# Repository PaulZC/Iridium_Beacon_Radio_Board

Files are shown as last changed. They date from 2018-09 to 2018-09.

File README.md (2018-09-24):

# Iridium 9603N Beacon Radio Board

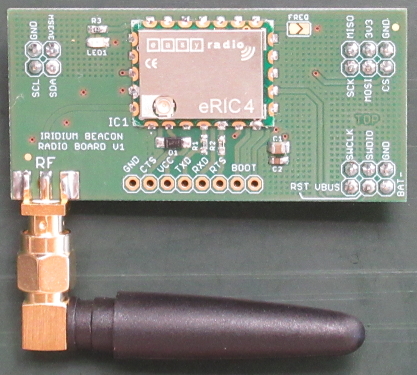
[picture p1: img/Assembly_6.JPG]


A radio board for the [Iridium 9603N Beacon](https://github.com/PaulZC/Iridium_9603_Beacon). Equipped with an
[LPRS eRIC4 or eRIC9 integrated radio module](http://www.lprs.co.uk/products/easyradio-ism-modules/eric-soc-rf-modules.html),
this board allows remote control of radio-enabled devices near the Iridium Beacon. E.g. a
[radio-enabled cut-down device](https://github.com/PaulZC/Pyrotechnic_Balloon_Cut-Down).

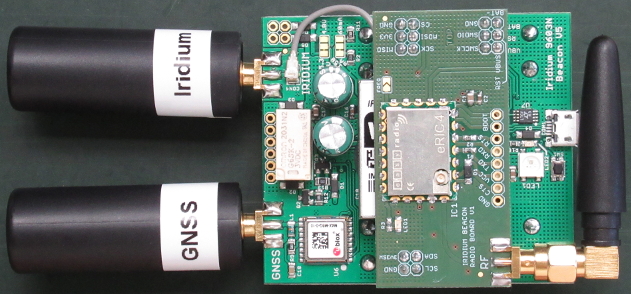
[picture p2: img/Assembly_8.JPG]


See [ASSEMBLY.md](https://github.com/PaulZC/Iridium_Beacon_Radio_Board/blob/master/ASSEMBLY.md) for details on how to assemble the PCB.

See [Iridium_Beacon_Radio_Board_V1.pdf](https://github.com/PaulZC/Iridium_Beacon_Radio_Board/blob/master/Iridium_Beacon_Radio_Board_V1.pdf) for the schematic,
layout and Bill Of Materials.

The [Eagle](https://github.com/PaulZC/Iridium_Beacon_Radio_Board/tree/master/Eagle) directory contains the schematic and pcb design files.

### License

This project is distributed under a Creative Commons Attribution + Share-alike (BY-SA) licence.
Please refer to section 5 of the licence for the “Disclaimer of Warranties and Limitation of Liability”.

Enjoy!

**_Paul_**

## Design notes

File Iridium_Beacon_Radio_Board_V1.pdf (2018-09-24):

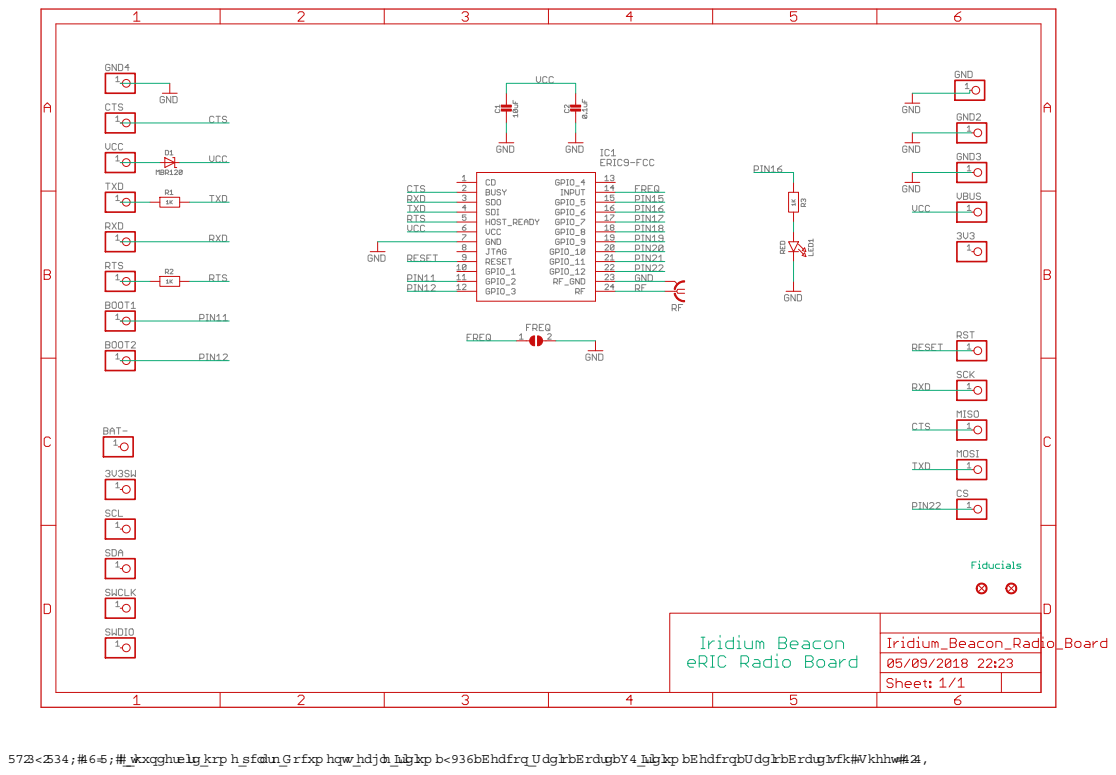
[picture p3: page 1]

thunderbird\hom e\pclark\D ocum ents\eagle\Iridium _9603_Beacon\R adio_Board_V1\Iridium _Beacon_R adio_Board.sch (Sheet: 1/1)

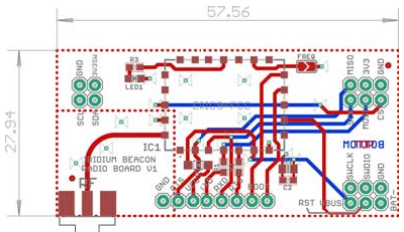
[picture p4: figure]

24/09/2018 13:29 \\thunderbird\hom e\pclark\D ocum ents\eagle\Iridium _9603_Beacon\R adio_Board_V1\Iridium _Beacon_R adio_Bo

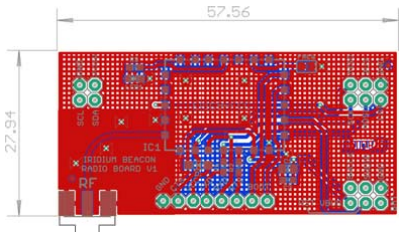
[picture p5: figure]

24/09/2018 13:29 \\thunderbird\hom e\pclark\D ocum ents\eagle\Iridium _9603_Beacon\R adio_Board_V1\Iridium _Beacon_R adio_Bo

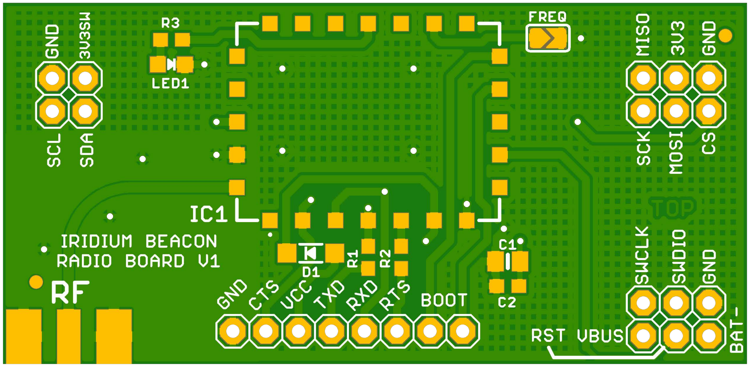
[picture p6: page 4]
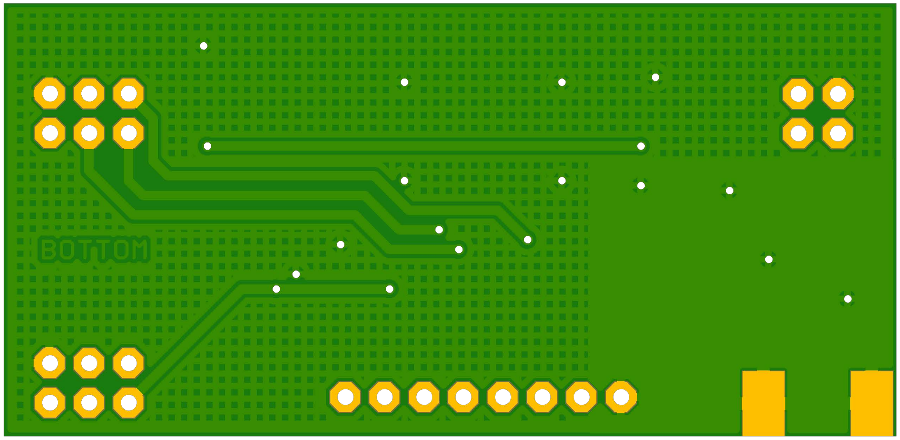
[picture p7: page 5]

Part | X | Y | Angle | Package Value | Manufacturer | Manufacturer Part No

Farnell
| | | | | | | Part No Mouser Part No | Description
Dimensions 57.56 | 27.94

Fiducials - for solder paste mask alignment:

FD1 | 55.88 | 25.40 | | | | | | Fiducial 1mm
FD2 | 2.54 | 6.35 | Fiducial 1mm

Surface Mount Components:

C1 | 39.05 | 7.94 | 180 0805 | 10uF | Murata | GCJ21BR71A106KE01L | 2781411 | MultiLayer Ceramic Capacitor; 10uF; 10V; 0805; X7R
C2 | 39.05 | 6.03 | 180 0603 | 0.1uF | Murata | GRM188R71H104JA93D 2688523 | MultiLayer Ceramic Capacitor; 0.1uF; 50V; 0603; X7R
D1 | 23.81 | 8.57 | 0 SOD-123 MBR120 ON SEMICONDUCTOR MBR120VLSFT1G | 1431044 | Schottky Rectifier; 20V; 1A; SOD-123
IC1 | 28.26 | 18.73 | 0 | ERIC4 | LPRS | ERIC4 | 2362439 | LPRS easy Radio Intelligent Controller 433MHz
| | | | ERIC9 | LPRS | ERIC9 | 2362440 | LPRS easy Radio Intelligent Controller 868/915MHz
LED1 | 13.02 | 23.18 | 270 2.0x1.25 RED | Wurth Electronik | 150080RS75000 | 2322077 710-150080RS75000 LED; Red; 20mA; 2V; 2.0x1.25mm
R1 | 28.26 | 8.26 | 90 0603 | 1K | Multicomp | MCWR06X1001FTL | 2447272 | Chip Resistor; Thick Film; 1k; 50V; 0603; 100mW
R2 | 30.8 | 8.26 | 90 0603 | 1K | Multicomp | MCWR06X1001FTL | 2447272 | Chip Resistor; Thick Film; 1k; 50V; 0603; 100mW
R3 | 13.02 | 25.08 | 180 0603 | 1K | Multicomp | MCWR06X1001FTL | 2447272 | Chip Resistor; Thick Film; 1k; 50V; 0603; 100mW

Non-surface mount components:

RF | SMA Jack Johnson | 142-0711-821 | 1019328 | SMA End Launch Jack

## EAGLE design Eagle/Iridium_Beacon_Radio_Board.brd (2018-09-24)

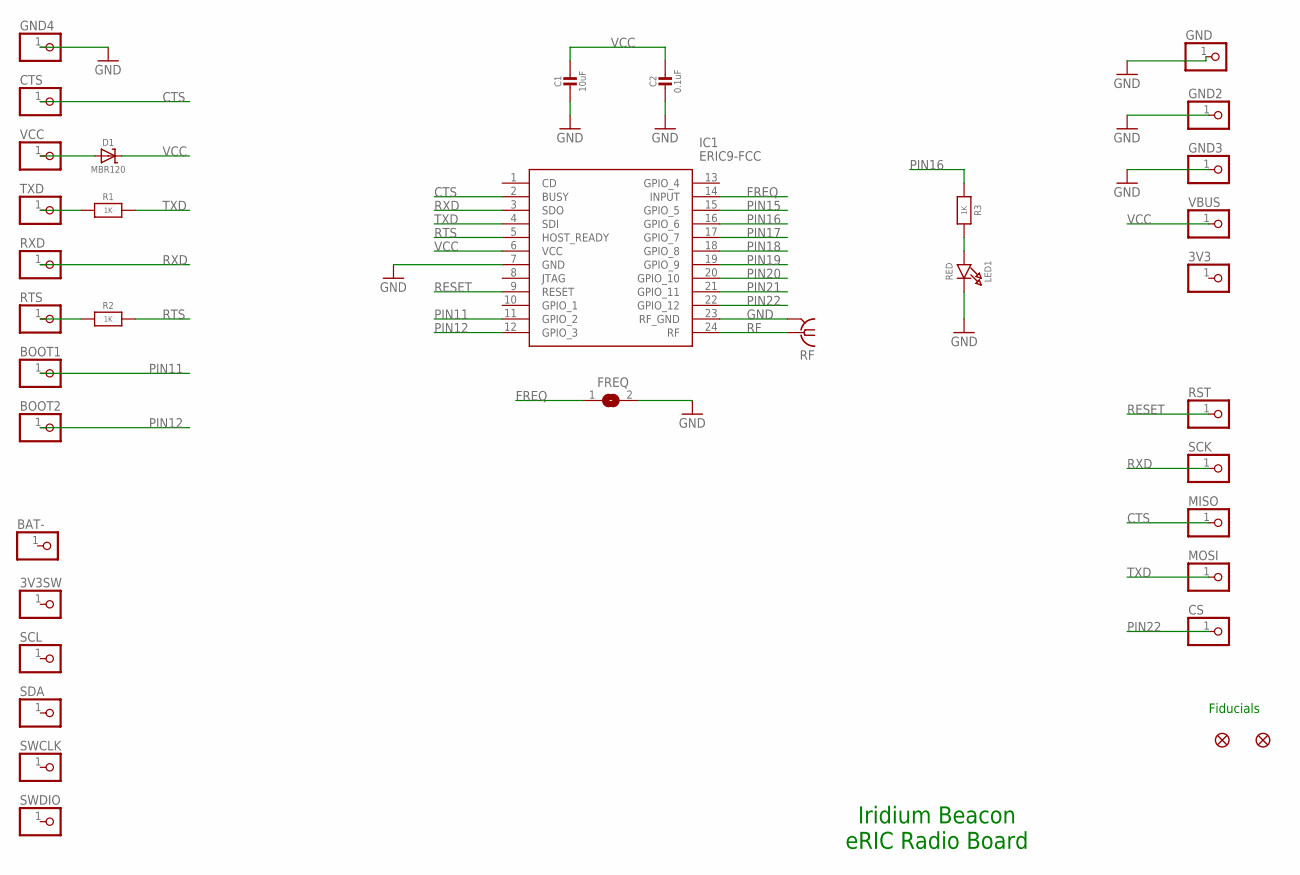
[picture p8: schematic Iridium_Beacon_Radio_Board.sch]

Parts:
3V3, 3V3SW: PINHD-1X1; 1X01
BAT-: PINHD-1X1; 1X01
BOOT1, BOOT2: PINHD-1X1; 1X01
C1: 10uF; 0805-NO
C2: 0.1uF; 0603-NO
CS: PINHD-1X1; 1X01
CTS: PINHD-1X1; 1X01
D1: MBR120; SOD-123
FD1, FD2: FIDUCIAL1X2; FIDUCIAL-1X2
FREQ: SOLDERJUMPER; SOLDERJUMPER_ARROW_NOPASTE
GND, GND2, GND3, GND4: PINHD-1X1; 1X01
IC1: ERIC9-FCC; ERIC4
LED1: RED; CHIPLED_0805_NOOUTLINE
MISO: PINHD-1X1; 1X01
MOSI: PINHD-1X1; 1X01
R1, R2, R3: 1K; 0603-NO
RF: SMA-142-0711-821/826; J502-ND-142-0711-821/826
RST: PINHD-1X1; 1X01
RTS: PINHD-1X1; 1X01
RXD: PINHD-1X1; 1X01
SCK: PINHD-1X1; 1X01
SCL: PINHD-1X1; 1X01
SDA: PINHD-1X1; 1X01
SWCLK: PINHD-1X1; 1X01
SWDIO: PINHD-1X1; 1X01
TXD: PINHD-1X1; 1X01
VBUS: PINHD-1X1; 1X01
VCC: PINHD-1X1; 1X01

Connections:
CTS: CTS.1, IC1.2 (BUSY), MISO.1
FREQ: FREQ.1, IC1.14 (INPUT)
GND: C1.2, C2.2, FREQ.2, GND.1, GND2.1, GND3.1, GND4.1, IC1.7 (GND), IC1.23 (RF_GND), LED1.C, RF.G@1 (2), RF.G@2 (2), RF.G@3 (2), RF.G@4 (2)
unnamed: LED1.A, R3.2
unnamed: R1.1, TXD.1
unnamed: R2.1, RTS.1
unnamed: D1.A, VCC.1
PIN11: BOOT1.1, IC1.11 (GPIO_2)
PIN12: BOOT2.1, IC1.12 (GPIO_3)
PIN15: IC1.15 (GPIO_5)
PIN16: IC1.16 (GPIO_6), R3.1
PIN17: IC1.17 (GPIO_7)
PIN18: IC1.18 (GPIO_8)
PIN19: IC1.19 (GPIO_9)
PIN20: IC1.20 (GPIO_10)
PIN21: IC1.21 (GPIO_11)
PIN22: CS.1, IC1.22 (GPIO_12)
RESET: IC1.9 (RESET), RST.1
RF: IC1.24 (RF), RF.1
RTS: IC1.5 (HOST_READY), R2.2
RXD: IC1.3 (SDO), RXD.1, SCK.1
TXD: IC1.4 (SDI), MOSI.1, R1.2
VCC: C1.1, C2.1, D1.C, IC1.6 (VCC), VBUS.1

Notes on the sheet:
Iridium Beacon eRIC Radio Board
Fiducials

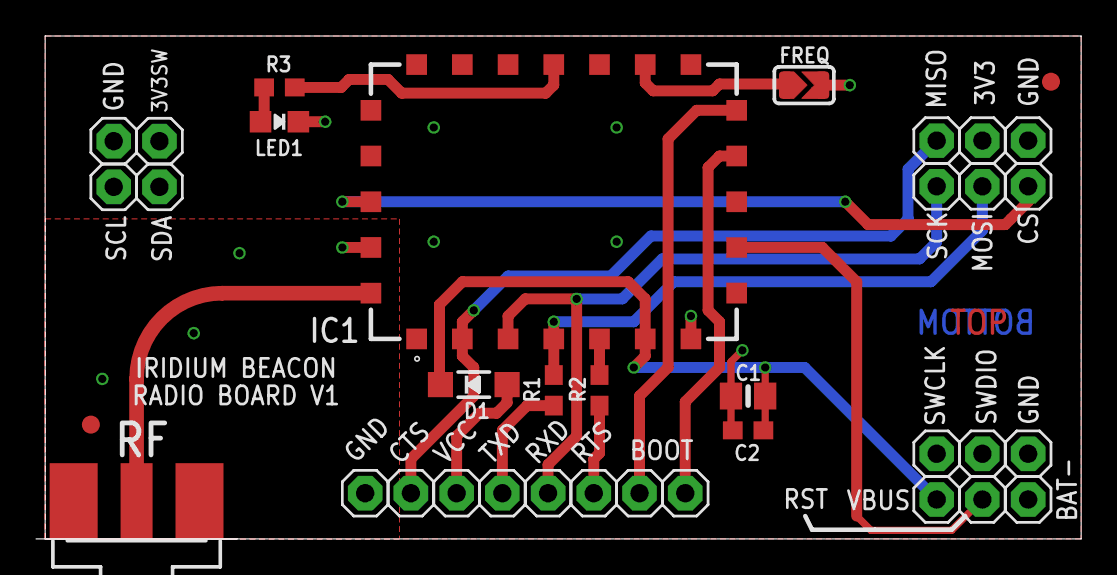
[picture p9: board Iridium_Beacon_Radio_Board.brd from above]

Board: 2 copper layers, 58.1 x 27.9 mm, 36 parts (0 on the bottom side), 17 nets.

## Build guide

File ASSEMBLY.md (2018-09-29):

# Iridium 9603N Beacon Radio Board

## Circuit Board Assembly



A radio board for the [Iridium 9603N Beacon](https://github.com/PaulZC/Iridium_9603_Beacon). Equipped with an
[LPRS eRIC4 or eRIC9 integrated radio module](http://www.lprs.co.uk/products/easyradio-ism-modules/eric-soc-rf-modules.html),
this board allows remote control of radio-enabled devices near the Iridium Beacon. E.g. a
[radio-enabled cut-down device](https://github.com/PaulZC/Pyrotechnic_Balloon_Cut-Down).

See [Iridium_Beacon_Radio_Board_V1.pdf](https://github.com/PaulZC/Iridium_Beacon_Radio_Board/blob/master/Iridium_Beacon_Radio_Board_V1.pdf) for the schematic,
layout and Bill Of Materials.

The [Eagle](https://github.com/PaulZC/Iridium_Beacon_Radio_Board/tree/master/Eagle) directory contains the schematic and pcb design files.

Here are the assembly instructions for V1 of the PCB:

### eRIC

The radio board uses the eRIC4 or eRIC9 [easyRadio Integrated Controller](http://www.lprs.co.uk/products/easyradio-ism-modules/eric-soc-rf-modules.html).

Either an eRIC4 or an eRIC9 can be installed. The eRIC4 operates at 402-470 MHz for Europe, APAC and China. The eRIC9 operates at 804-940 MHz for Europe,
North & South America, India and China. Solder the _FREQ_ split pad to select the eRIC9 915 MHz band.

The eRIC will come pre-programmed with easyRadio V1.5.5 and is ready to use.

You can find the datasheet for the eRIC on the LPRS website:
- http://www.lprs.co.uk/products/easyradio-ism-modules/eric-soc-rf-modules.html
- http://www.lprs.co.uk/assets/files/eRIC4_9_Datasheet_1.34.pdf

### Blank PCB

Start by having the blank PCBs manufactured. If you are based in the UK or Europe, I can recommend
[Multi-CB](https://www.multi-circuit-boards.eu/en/index.html) who can manufacture PCBs in 1-8 working days and
can process the Eagle .brd file direct - there's no need to generate Gerber files.

My recommended options are:
- Layers: 2 layers
- Format: single pieces
- Surface finish: chemical gold (ENIG)
- Material: FR4, 1.55mm
- Cu layers: 35um
- Solder stop: both sides, green
- Marking print: top side, white

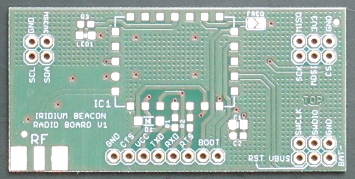
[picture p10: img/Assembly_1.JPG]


### Add the surface mount components

Solder the surface mount components onto the board by hand. There are many good surface mount soldering guides available on the web, including
[this one](https://www.youtube.com/watch?v=QzoPxvIM2qE).

Use a cotton swab dipped in Isopropyl Alcohol (IPA / Propanol / rubbing alcohol) to remove any flux residue.

All being well, your PCB should look like this:

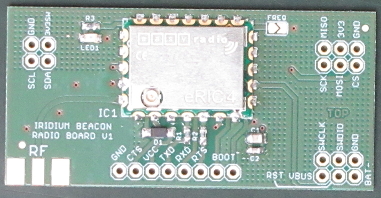
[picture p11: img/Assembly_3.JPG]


### Add the non-surface mount components

The non-surface mount components (SMA connector and header pins) can now be soldered into place.

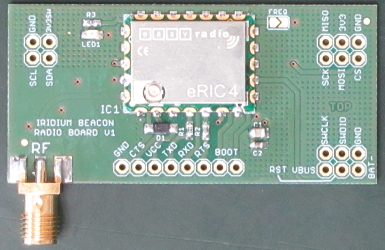
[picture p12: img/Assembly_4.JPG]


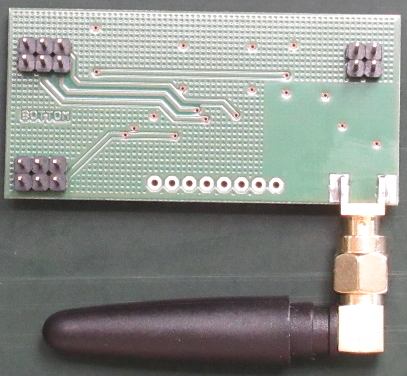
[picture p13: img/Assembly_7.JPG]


### Lacquer the PCB

I do recommend giving the PCB a coat of lacquer, especially if you are intending to use it on a balloon flight.
Cover all of the surface mount components with [Acrylic Protective Lacquer (conformal coating)](https://uk.rs-online.com/web/p/conformal-coatings/3217324/).

### LED

LED1 will flash once per second when the eRIC is powered up and not in power-save mode.

### I/O pins

The eRIC TxD, RxD, CTS and RTS pins are connected to 0.1" pads on the edge of the circuit board. The order of these pads matches the order of the pins of an FTDI
TTL-232R-3V3 USB to TTL serial cable. The eRIC can be reprogrammed via the FTDI cable if required.

Two extra pads are connected to the eRIC bootloader pins (Pin11 and Pin12). The eRIC will enter bootloader mode if these pads are shorted together on reset
or power-up. LED1 will be lit continuously when the eRIC is in bootloader mode.

### Antennas

Recommended antenna for the eRIC4 is:
- LPRS ANT-SR433 (Farnell part 2096221)

Recommended antenna for the eRIC9 is:
- LPRS ANT-SR900 (Farnell part 2096219)

http://www.lprs.co.uk/products/antennas-cables-connectors/stubby-antennas.html

The horizontal antenna orientation is important if the Iridium Beacon is located below the cut-down device on the balloon cord.

### Iridium Beacon Connections

The radio board is designed to sit on top of the Iridium 9603N module and connect to the IO pads on the Iridium Beacon board. You will need to solder three sockets
onto the Iridium Beacon board for the radio board to plug into:

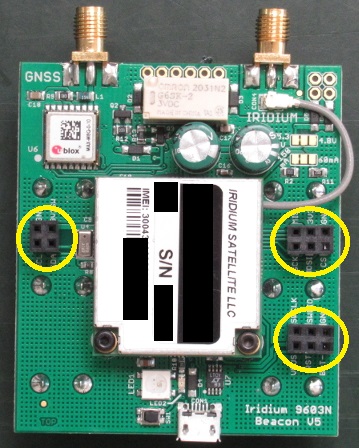
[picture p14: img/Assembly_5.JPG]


- The 3+3 Way sockets are Harwin M20-7830346 (Farnell part 7991983)
- The 2+2 Way socket is Harwin M20-7830246 (Farnell part 7991975)



### How much does it weigh?

Fully assembled, including Energiser® Ultimate Lithium AA batteries and all three antennas, the total weight of the Iridium Beacon plus
Radio Board is 129.2g

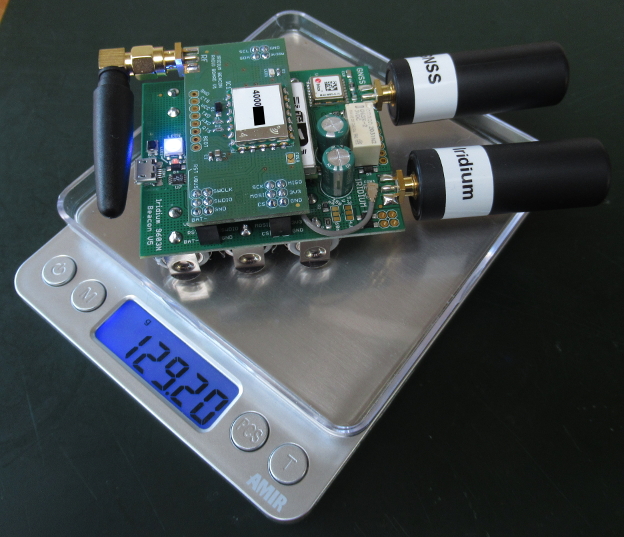
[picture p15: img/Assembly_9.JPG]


### The Small Print

This project is distributed under a Creative Commons Attribution + Share-alike (BY-SA) licence.
Please refer to section 5 of the licence for the "Disclaimer of Warranties and Limitation of Liability".

Enjoy!

**_Paul_**

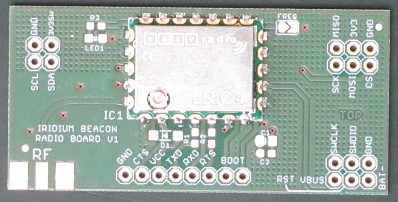
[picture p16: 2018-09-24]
img/Assembly_2.JPG

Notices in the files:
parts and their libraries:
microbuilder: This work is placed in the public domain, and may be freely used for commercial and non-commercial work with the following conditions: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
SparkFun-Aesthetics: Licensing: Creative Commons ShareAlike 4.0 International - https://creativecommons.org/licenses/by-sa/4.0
